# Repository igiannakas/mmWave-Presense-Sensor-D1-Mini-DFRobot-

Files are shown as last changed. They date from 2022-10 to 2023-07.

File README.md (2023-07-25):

# Introduction
This is a step by step guide on how to build an mmWave presence detection using DFRobot SEN0395, D1 Mini ESP-8266 and ESPHome. 

The custom module in the code above is used to implement a room presense sensor and exposes the presense detection sensor and the radar's configuration variables to Home Assistant via the ESPHome integration.

For a more advanced multi-sensor, including temperature, humidity, air quality and air pressure refer to my project here: https://github.com/igiannakas/Presense-Temperature-Humidity-Air-Quality-multi-sensor-DFRobot-SHT35-or-BME680-

This is based on the excellent work done by CRlogic in the HA forums and documented here: https://github.com/hjmcnew/esphome-hs2xx3a-custom-component/tree/release

In this fork of the code, the code is adapted to:
1. Deliver a very compact build as the DFRobot sensor is stacked on top of the D1 Mini
2. Trimmed down the code by CRLogic to improve stability for the low power D1 Mini. The sensor is purely focused on presense and motion detection, which is the core use case.
3. Prettify the exposed sensor names to Home Assistant to reflect the name of the room the sensor is in
4. Contain the full sensor yaml configuration to simplify the setup process

# Bill of Materials:
To make this DIY room presense sensor you'll need the below components:
1. D1 Mini
2. DFRobot SEN0395 (from Digi Key, Mouser, Arrow.com, Farnell.com, AliExpress)
3. Mini USB cable and a USB power supply (I use my old phone chargers)
4. Soldering iron
5. 5 cm / 2 inch of wire
6. Optional: 3d printed case (either the one in the folder above or the slightly larger case I've published here if you are using an ESP32 Mini: https://www.printables.com/model/520547-esp32-temperature-and-optional-mmwave-radar-presen)

# Wiring instructions:
To get the smallest possible size we stack the sensor on top of the D1 Mini using the pins that come with the D1 mini. The wiring diagram below reflects a stacked configuration:
Sensor Pin -> D1 Mini Pin
1. TX -> D1
2. RX -> D2
3. IO1 -> not connected
4. IO2 -> D0 (using the wire)
5. G -> G
6. V -> 5V

For the D1, D2, G and 5V pins we will use header and pin connectors soldered on the D1 mini and the mmWave sensor. The D0 - IO2 connection happens via a wire which is soldered on the D0 pad of the D1 mini and the IO2 pad of the sensor.

# Assembly images

Solder the header connectors and the single wire to the D1 Mini as below:
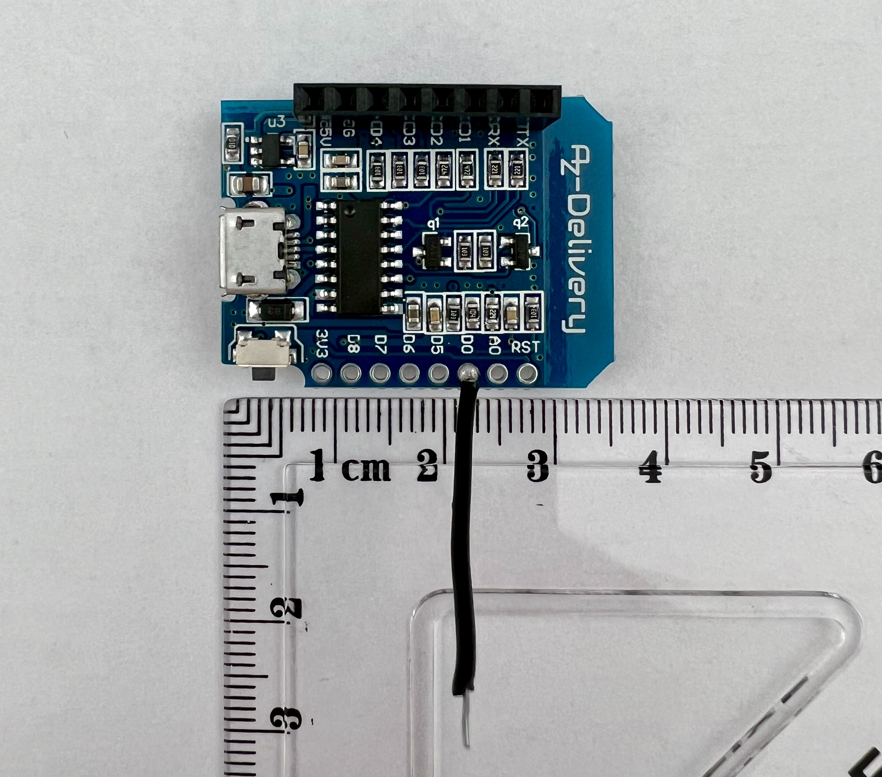
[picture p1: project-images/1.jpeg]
D1 Mini connections


Solder the pins to the outer two sets of pads on the sensor (TX, RX, G, V) and then solder the single wire to IO2
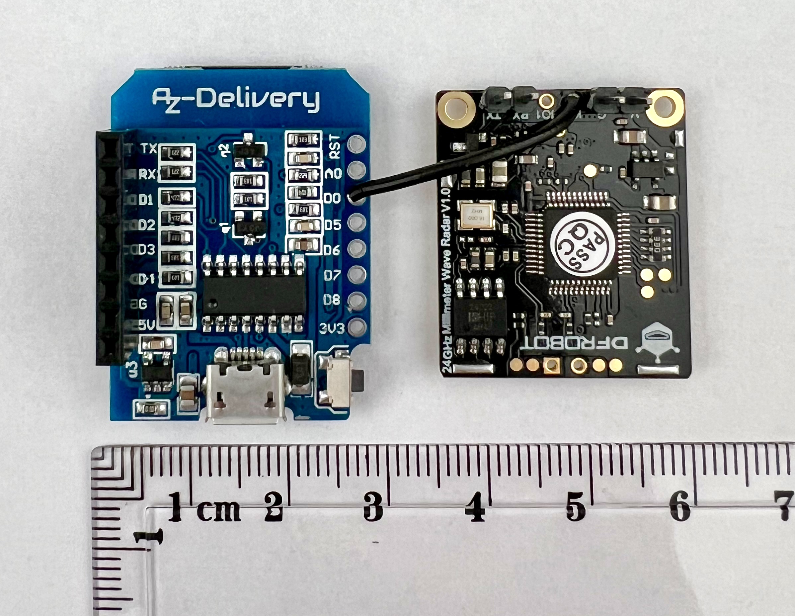
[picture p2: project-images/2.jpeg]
Sensor connections


Plug in the sensor to the D1 mini,making sure the V sensor pin is aligned to the 5V header on the D1 mini
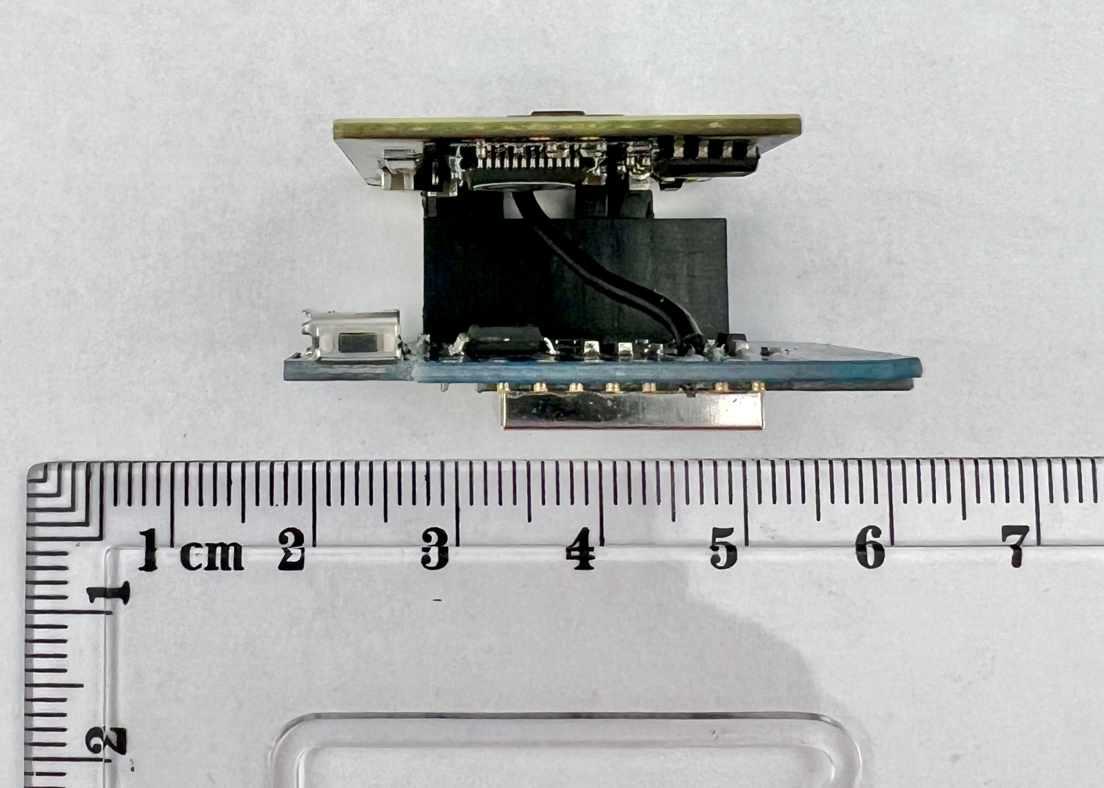
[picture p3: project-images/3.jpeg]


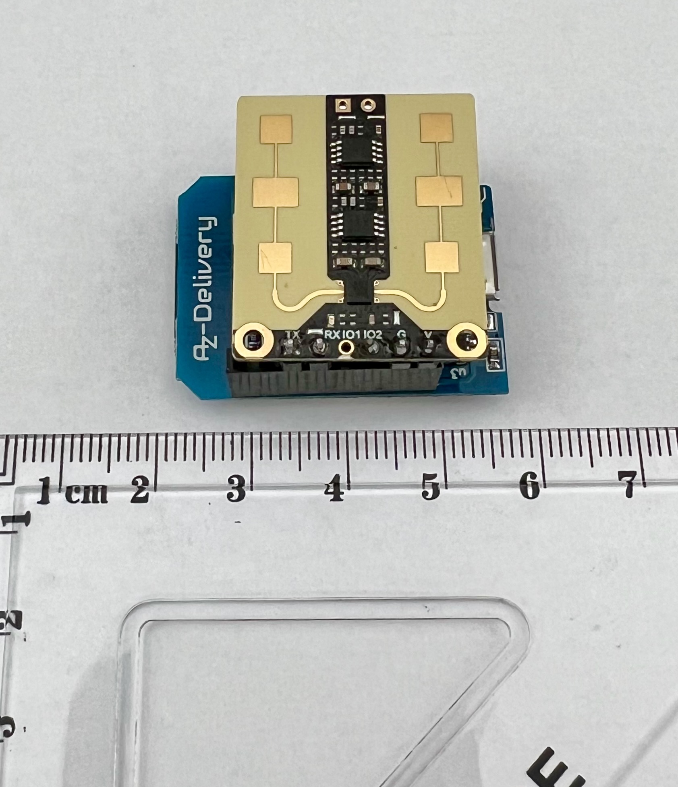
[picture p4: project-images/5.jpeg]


As you can see this is a super compact sensor, barely bigger than the D1 mini itself.
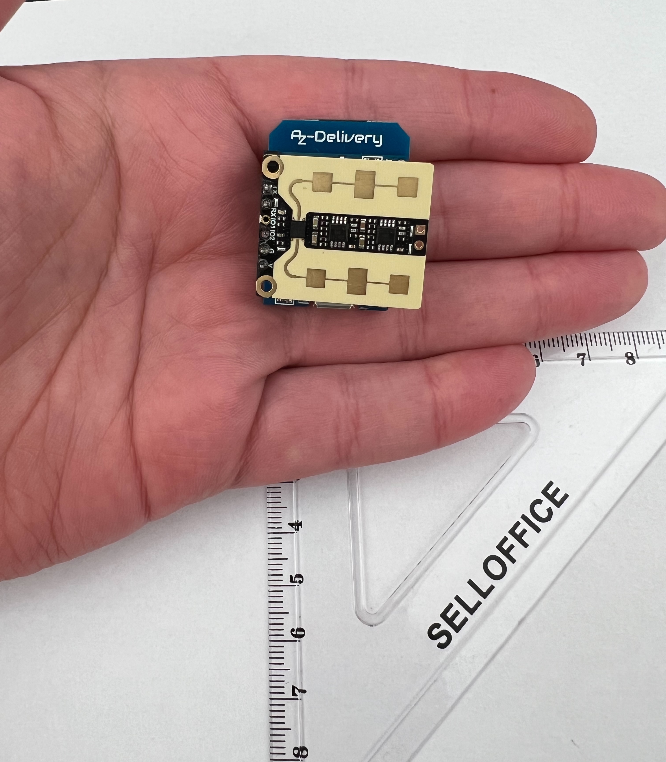
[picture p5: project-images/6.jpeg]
Sensor assembled


# Installing ESPHome and the mmWave code

1. Setup your esphome environment. For instructions: https://esphome.io
2. Clone this repository to your build environment. Download the code zip and unpack it in your esphome build directory
3. Open the sensor.yaml file and modify the following variables to match your setup:

**device_name**: the sensor's device name. This must be in lower case and any words separated with hyphens (-). For example: living-room-occupancy-sensor<br>
**device_name_pretty**: This is the name of the occupancy binary sensor that will be exposed to home assistant. It can be upper and lower case and can contain spaces. For example: Room Name Occupancy Sensor<br>
**ssid**: type your 2.4ghz wifi SSID<br>
**wifi_password**: type in your wifi password<br>

4. Do not modify the uart_tx_pin, uart_rx_pin, gpio_pin values unless you're using a different pinout connection.
5. Deploy the code. I have installed esphome on my mac so I use the following command to deploy the code: esphome run sensor.yaml . If it is a fresh D1 Mini, it doesnt contain the esphome code. For the first flash, you'll need to plug it in to your computer or HA box and flash it. Any subsequent updates will happen over the air. 

For a tutorial on how to setup your esphome instance read up here:
1. From the command line & using docker: https://esphome.io/guides/getting_started_command_line.html
2. From home assistant OS: https://esphome.io/guides/getting_started_hassio.html

# Setting the sensor up in HomeAssistant and configuring its parameters
The sensor should be autodetected in your homeassistant dashboard. Go to Settings - Devices & Services and add the integration. Then you should be presented with the following device dashboard:

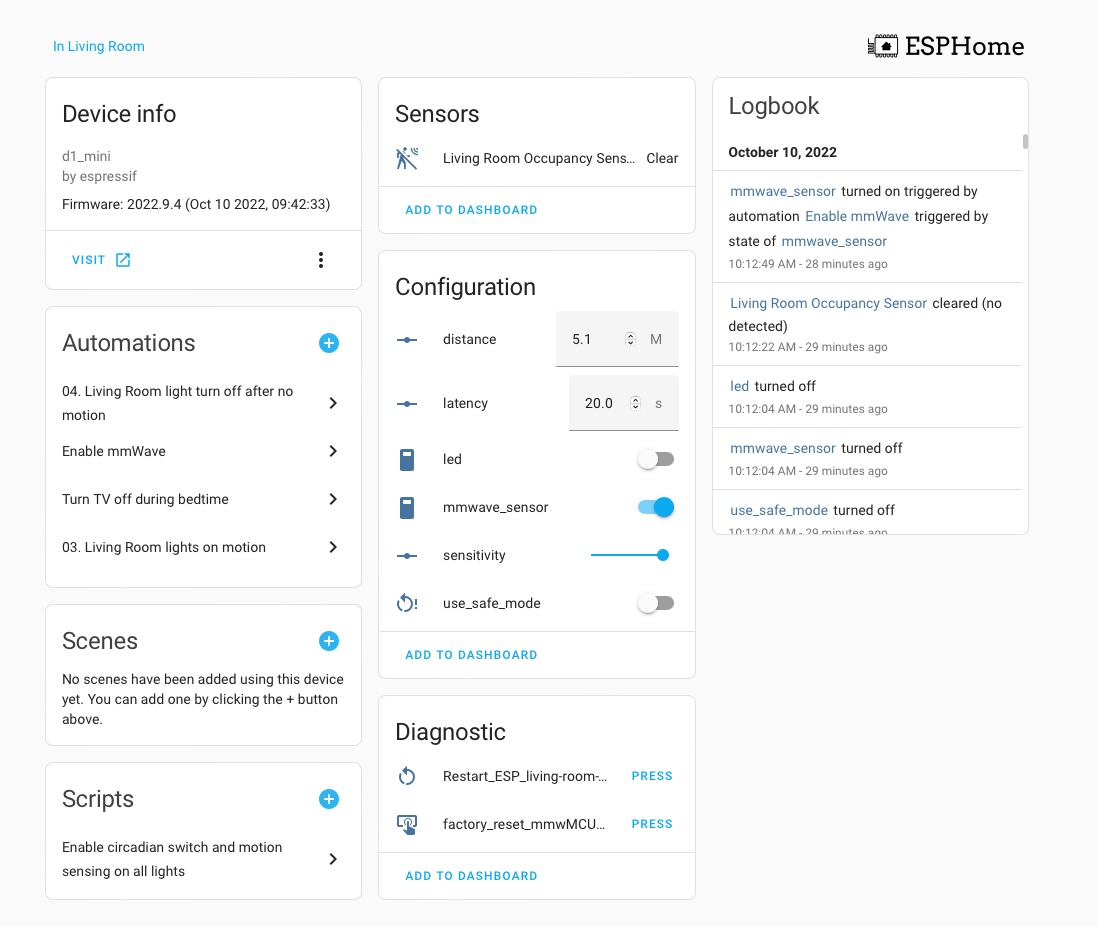
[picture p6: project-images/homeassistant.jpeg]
Homeassistant dashboard


Here you can:
1. **See the occupancy sensor value (clear / detected)**. This is the sensor you will use in your automations. 
2. **Distance**: this variable can be used to set the maximum distance the sensor can see. It defaults to the sensor default value.
3. **Latency**: this is the sensor cool down period, i.e. how long should no presence be detected before the occupancy sensor is set to "Clear". It defaults to the sensor default value.
4. **Led**: a toggle switch to turn the sensor LED on or off. On initial setup it defaults to off but the sensor LED is on and blinking. So if you want to turn the sensor LED off, switch it on, wait for 10 seconds then switch it off again. The value should now persist in the sensor's memory
5. **mmwave_sensor**: This toggle switch turns the motion sensor (radar) on or off. It defaults to on, but is reported as off until the first time presense is detected. Can be usefull if you need to disable motion sensing from an automation or script.
6. **Sensitivity**: How sensitive the sensor is to movement. The Radar sensor is **very** sensitive to movement in order to deliver meaningfull presense detection but it can be triggered falsely with the movement of curtains, clothes etc. If you want to reduce sensitivity reduce this number. It defaults to 7, which is a good balance but if you are finding that the sensor reporting as clear when the room is occupied increase this to 9.
7. **use_safe_mode**: restarts the D1 mini in safe mode
8. **Restart**: restarts the sensor
9. **Factory reset mmWMCU**: resets the radar to its factory default settings. (distance, latency, led, sensitivity)

The sensor distance, latency, mmwave_sensor, sensitivity values are read from the radar's presistent memory. They persist reboots but reporting the values to HomeAssistant is delayed. It will take 5-10 minutes after you reboot the D1 Mini for the values to be reported so be patient until they are populated before making any changes.

Every time you change a value you need to wait ~15 - 20 seconds for the value to be written to the DFRobot radar sensor memory and for the radar to restart. While the D1 mini is writing the values to the radar's memory you'll see the LED light turn red. Once it starts blinking or is off (depending on your settings) the values are now written in memory and are persistent through reboots. 

# Sensor case
I've designed a basic case for the sensor which should provide a snug fit to its components. The STL file is included in the respository above. The case has been tested with the D1 mini and the above sensor and also with a D1 mini and an LD2410 mmwave sensor.

There are two linds in the file - a tight and a loose fitting one. Depending on your 3d Printer tolerance print one of the two lids to allow for friction fit.

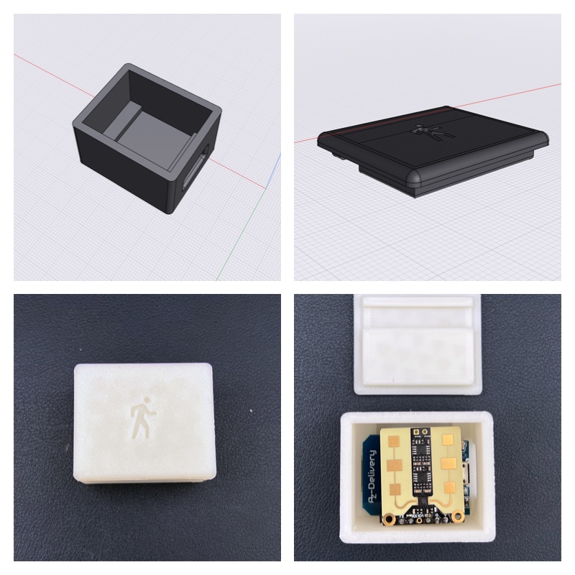
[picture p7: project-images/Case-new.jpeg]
Case


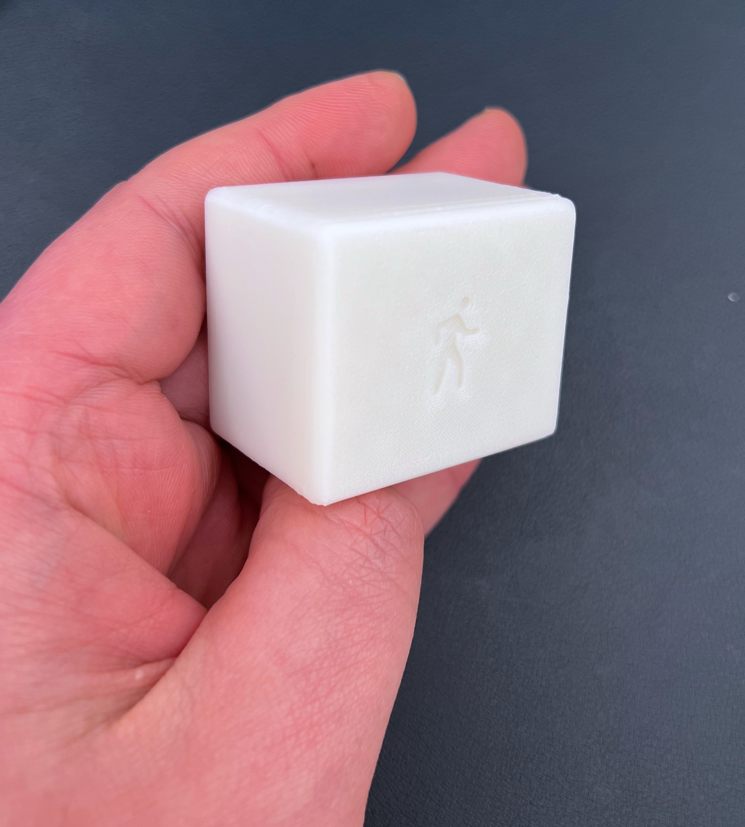
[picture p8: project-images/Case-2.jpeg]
Case


# Troubleshooting
What I have found is that the sensor is very sensitive to motion (which is what you want in order to get room presense). However, that might lead to false positives, when for example, you have a window open and objects move. 

In that situation, your best bet is to experiment with placement, the distance parameter and lastly if everything else fails, the sensitivity parameter. You dont want sensitivity too low, as it wont be able to detect the micro movements that humans do when siting around though!

Also if you are sleeping on the sofa and covered with a blanket the sensor might not detect you - a larger cooldown period (latency) can help here but you're trading off the lights being on for longer when noone is actually present.

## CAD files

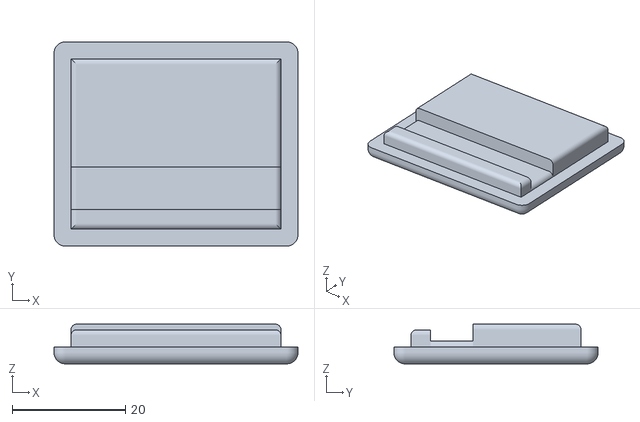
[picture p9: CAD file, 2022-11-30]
Case STL model/mmWave lid tight - v7.stl
43.0 x 36.0 x 7.00

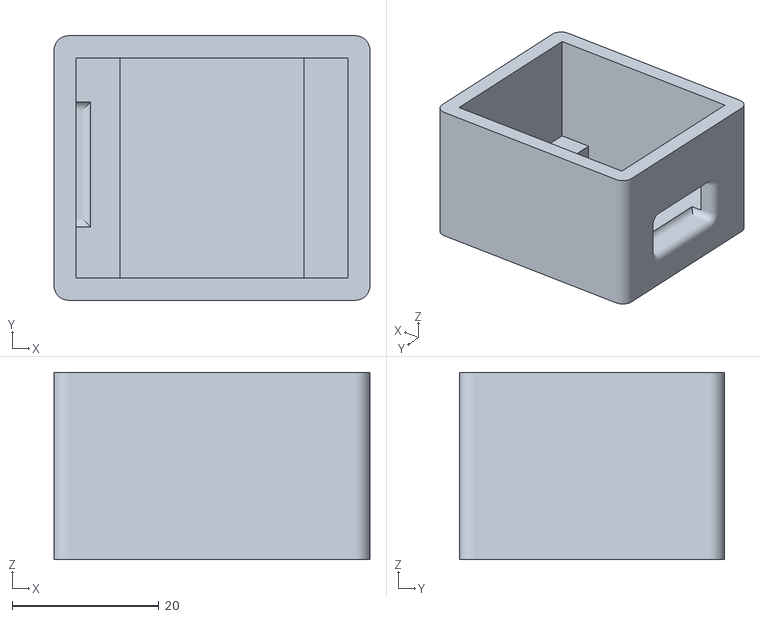
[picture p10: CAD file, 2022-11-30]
Case STL model/mmWave bottom case v7.stl
43.0 x 36.0 x 25.5

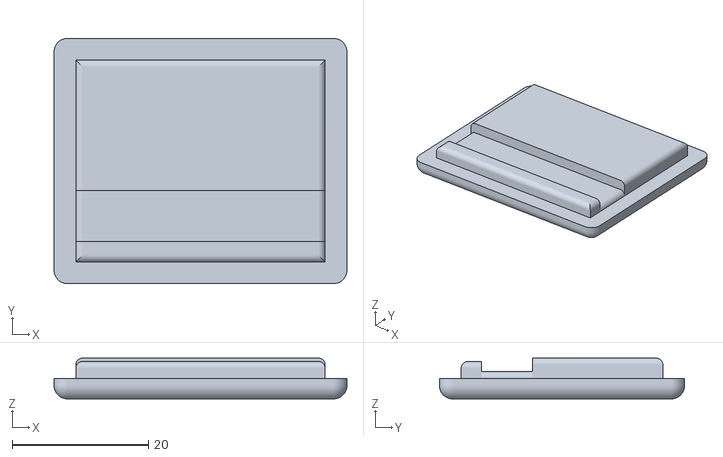
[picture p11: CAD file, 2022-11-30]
Case STL model/mmWave lid loose - v7.stl
43.0 x 36.0 x 6.00

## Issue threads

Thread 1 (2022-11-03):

A esp32 d1 mini is perfect

stofakiller, 2022-11-03:
Hi, i tried a esp32 d1 mini, with 2 rows of pins on either side. and i can connect the sensor directly. pin 21/22 for rx/tx, 16/17 for the IO1 (not used) and IO2 from the sensor and vcc and gnd...
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

Ramblurr, 2022-12-30:
@igiannakas Would you be willing to help scale the STL to fit the esp32 d1 mini? I'm not very talented with CAD unfortunately.

My calipers tell me that the ESP32 d1 mini PCB is 31.78 mm wide x 39.09mm long. If you measure the length from one end of the PCB to the other and include the micro usb socket then the length is about 39.9mm

igiannakas, 2022-12-30:
> @igiannakas Would you be willing to help scale the STL to fit the esp32 d1 mini? I'm not very talented with CAD unfortunately.
>
> My calipers tell me that the ESP32 d1 mini PCB is 31.78 mm wide x 39.09mm long. If you measure the length from one end of the PCB to the other and include the micro usb socket then the length is about 39.9mm

Should be able to scale it up to the size you want in your 3D printer slicer? No need for CAD to bump up its dimensions?

nickelnine, 2023-01-19:
@stofakiller , did you happen to print a case to fit the ESP32 version?

stofakiller, 2023-01-20:
Hi,Sorry not Venlig hilsen/Best Regards,Jan LarsenDen 20. jan. 2023 kl. 00.50 skrev nickelnine ***@***.***>:
@stofakiller , did you happen to print a case to fit the ESP32 version?

—Reply to this email directly, view it on GitHub, or unsubscribe.You are receiving this because you were mentioned.Message ID: ***@***.***>

Closed 2022-11-30.

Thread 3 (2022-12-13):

combine in one yaml

smic717394, 2022-12-13:
First of all, thank you for the detailed post. The way it worked for me was creating a folder called mmwave in the esphome directory just to organise things, inside I copied the 2 folders header and packages. I had to modify the path in the yaml to the mmwave/packages/leapmmw_sensor.yml and then edited the sensor yaml and change the header path to mmwave/header/leapmmw_sensor.h, I guess I could just puth both header and sensor in one folder.

I have 2 questions, Would it be posible to combine the sensor and header in one yaml that flases into the mini d1, and second, in case this is not posible, say you have 3 units, do I need to create 3 folders with 3 sensor.h and sensor.yml files, o could I just redirect all to the same path?

igiannakas, 2023-07-25:
They can all redirect to the same path - that is the reason why I split them out to multiple files. You only need one "sensor.yaml" per sensor. They can all be in the root directory, with the remaining items (.h / leapmmw_sensor.yml) reused.

Closed 2023-07-25.

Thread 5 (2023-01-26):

Settings wont be saved

fwartner, 2023-01-26:
I have a problem with saving the settings.
Once I reload the page, the settings I made are gone. Either in HA or the webinterface.

Running on the latest esphome version: 2022.12.7

igiannakas, 2023-01-26:
Try waiting a few seconds between changing one setting and then changing another. The radar needs time to save each one individually.

fwartner, 2023-01-27:
Doesn't have any effect.. :-/

igiannakas, 2023-01-27:
It may be a wiring issue - can you post a screenshot from the complete HA device page? Are you seeing the sensor reporting back the preset distance and sensitivity values in home assistant?On 27 Jan 2023, at 08:53, Florian Wartner ***@***.***> wrote:
Doesn't have any effect.. :-/

—Reply to this email directly, view it on GitHub, or unsubscribe.You are receiving this because you commented.Message ID: ***@***.***>

fwartner, 2023-01-27:
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

Nothing really changed when I try to update anything. Like I said yesterday.. Once I reload the page, any setting is resettet.

fwartner, 2023-01-27:
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

igiannakas, 2023-01-27:
As you are not seeing the default values in the home assistant dashboard it is a connection error. Check that the wiring is done correctly - tx to rx and vice versa and that the motion detection pin is connected correctly.On 27 Jan 2023, at 09:06, Florian Wartner ***@***.***> wrote:

—Reply to this email directly, view it on GitHub, or unsubscribe.You are receiving this because you commented.Message ID: ***@***.***>

igiannakas, 2023-01-27:
This happens because serial communication is not established. This is usually due to a wiring issue or your pin out in the config is wrong.

fwartner, 2023-01-28:
I was indeed the wiring ^^'

Thank you for the help you provided!

Closed 2023-01-28.

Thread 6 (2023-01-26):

HA shows me always recognized

fwartner, 2023-01-26:
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

It's actually useless..

igiannakas, 2023-01-26:
Check if your radar is not picking up micro motions from a fan, air drafts, moving clothing etc. reduce sensitivity on the radar.

have been using them for the past 6 months and they have been reliable so the code is working, but the setup needs tweaking.

fwartner, 2023-01-27:
Nah.. Doesn't work.. :-/

ivishaltejwani, 2023-05-04:
> Check if your radar is not picking up micro motions from a fan, air drafts, moving clothing etc. reduce sensitivity on the radar.
>
> have been using them for the past 6 months and they have been reliable so the code is working, but the setup needs tweaking.

any idea how to change sensitivity on arduino ide , example through blynk slider?

Closed 2023-01-28.

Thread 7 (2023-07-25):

Can't change names of distance, latency, or sensitivity sensors

Mike1082, 2023-07-25:
First of all, thank you for sharing this. Out of the box for one sensor it works amazingly well.

My issue is that I would like to run many of these. When I deploy the first one, my friendly name does not get used for the distance, latency, or sensitivity sensors. For instance, "distance" is just called "number.distance" as opposed to "number.sensor-name-distance". I tried updating the leapmmw_sensor.yml file by changing the names (while leaving the id as-is) but with the 3 mentioned sensors, once I change those names, they will no longer update in HA with values stored in the device. They just look empty, even after waiting a very long time.

I tested this by going back and one-by-one putting the original "names" back, and as I did that, the values started appearing in HA and working as expected.

I believe that the issue is the functions in the header file are referring to the Name, as opposed to the id.

For example from leapmmw_sensor.yml:

```
number:
  - platform: template
    name: ${device_name_pretty} Distance #original value: distance
    id: distance # do not change
    entity_category: config
    min_value: 0.15
    max_value: 9.45
    step: 0.15
    unit_of_measurement: M
    mode: box
    lambda: |-
      leapmmw(id(uart_bus)).getmmwConf("getRange");
      return {};
    set_action:
      - switch.turn_off: mmwave_sensor
      - delay: 2s
      - uart.write: !lambda
          std::string range = "setRange 0 " + str_sprintf("%.2f", x);
          return std::vector<unsigned char>(range.begin(), range.end());
      - delay: 3s
      - switch.turn_on: mmwave_sensor
```

and from leapmmw_sensor.h:

```
// leapMMW:/>getRange
          if (getline.substr(0, 18) == "leapMMW:/>getRange" || getline.substr(0, 8) == "getRange") {
            std::string getRange = line.substr(15, 4);
            if (getRange.empty()) {
              ESP_LOGD("custom", "Did not find a value for getRange");
            } else {
              ESP_LOGD("custom", "The value of getRange is: %f", parse_number<float>(getRange).value());
              publishNumber("distance", parse_number<float>(getRange).value());
            }
          }
```

Once I change the "name" in the yml file, the function `publishNumber("distance", parse_number<float>(getRange).value());` no longer seems to work.

Is there a better way to have all of the entities associated with the device have names prefixed with the device name?

Thanks!

igiannakas, 2023-07-25:
Excellent,
Glad it worked as well for you! I’ve also deployed it on my setup too :)

Mike1082, 2023-07-25:
I was going to ask about adding additional sensors, then I realized you have another device with temp/humidity and another STL for a case... you f'in rock man. Is there any reason I couldn't do the same thing without going to an ESP32 version of the D1? I just bought a pack of D1 Minis with USB-C and 8266. They should be able to support one more sensor, and maybe a push button, right?

igiannakas, 2023-07-25:
Hey! Yes you can do it with an esp8266 - the wiring is a bit more tight space wise but it works ok.

The only reason i went for an esp32 for the combo sensor is because I wanted to try an esp32!

The same code from the other repo should work if you replace the pins with the ones your 8266 uses.

igiannakas, 2023-07-25:
Ps. If you try the other case with an 8266 you’ll need to enlarge the square cut out for the chip a bit as the d1 mini has it moved more to the left compared to the esp32 mini. I’ve included the step files on printables so it should be a very quick mod.

Closed 2023-07-25.

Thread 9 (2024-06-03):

Detection Segment Support

54Comet, 2024-06-03:
https://esphome.io/components/dfrobot_sen0395.html

> detection_segments (Optional, list): A list of detection segments. A segment specifies from where to where detection should trigger. One to four segments and ranges from 0cm to 9m may be specified. Distances should be defined in steps of 15cm. Note that the specified ranges are rounded internally. Segments can be defined in a one or two dimensional list. Pairs of values must be defined (from distance to distance). The default is one range from 0cm to 3m.

Would it be possible for this project to allow configuring the up to 4 detection segments that the sen0395 supports?  Currently I think the `id: distance` variable is essentially allowing a single segment to be set.

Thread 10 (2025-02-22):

Esp home 2025 does not allow custom components anymore

napalmcsr, 2025-02-22:
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

INFO ESPHome 2025.2.0
INFO Reading configuration /config/esphome/Family-room-mmPresence.yaml...
Failed config

sensor.custom: [source /config/esphome/mmwave-d1mini-main/packages/leapmmw_sensor.yml:40]

  The "custom" component has been removed. Consider conversion to an external component.
  https://esphome.io/guides/contributing#a-note-about-custom-components.
  platform: custom
  lambda: auto s = new leapmmw(id(uart_bus));
  App.register_component(s);
  return {};
  sensors:

napalmcsr, 2025-02-22:
I don't have the expertise to fix this... Maybe someday...

momoz, 2025-03-11:
anyone look through this and have a fix?

igiannakas, 2025-03-12:
Hi there thank you for this. I hadn’t compiled my sensors in a while as they have been working fine. Just seen that this is now deprecated.

I’ll update the repo over the next few days hopefully to address this.

DrFate09, 2025-03-15:
I was able to fix my presence sensor by using the fixed code for ESP here, https://github.com/DuncanIdahoCT/DFRobot-mmWave-Radar-dfrobot_sen0395

scotti-fletcher, 2025-05-14:
@DrFate09 would you mind sharing your code?

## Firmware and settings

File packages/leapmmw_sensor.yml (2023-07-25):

substitutions:
  # include the header file with the UART parsing logic 
  header_file: header/leapmmw_sensor.h

esphome:
  name: ${device_name}
  includes:
    - ${header_file}

#logger:
#  logs:
#    sensor: DEBUG # reduced logging to minimize web_server target overload..

uart:
  id: uart_bus
  tx_pin: ${uart_tx_pin}
  rx_pin: ${uart_rx_pin}
  baud_rate: 115200


## sensor definitions

binary_sensor:
  - platform: gpio
    name: "${device_name_pretty}"
    id: mmwave_presence_detection
    device_class: motion
    pin:
      number: ${gpio_pin}
      mode: INPUT_PULLDOWN
    # when motion is detected, the radar sensor is on so publish radar state to HA
    on_press:
      then:
        lambda: !lambda |-
          if (!id(mmwave_sensor).state) {
            id(mmwave_sensor).publish_state(true);
          }
    
sensor:      
  - platform: custom
    lambda: |-
      auto s = new leapmmw(id(uart_bus));
      App.register_component(s);
      return {};
    sensors:
      
switch:
  - platform: safe_mode
    name: use_safe_mode

  - platform: template
    name: "${device_name_pretty} mmwave_sensor"
    id: mmwave_sensor # do not change
    entity_category: config
    optimistic: true
    turn_on_action:
      - uart.write: "setUartOutput 1 0"
      - delay: 1s
      - uart.write: "saveConfig"
      - delay: 4s 
      - uart.write: "sensorStart"
    turn_off_action:
      - uart.write: "sensorStop"
      - delay: 2s

  - platform: template
    name: "${device_name_pretty} led"
    id: led  # do not change
    entity_category: config
    optimistic: true
    turn_on_action:
      - switch.turn_off: mmwave_sensor
      - delay: 2s
      - uart.write: "setLedMode 1 0"
      - delay: 3s
      - lambda: |-
          leapmmw(id(uart_bus)).getmmwConf("getLedMode 1");
      - delay: 2s 
      - switch.turn_on: mmwave_sensor
    turn_off_action:
      - switch.turn_off: mmwave_sensor
      - delay: 2s
      - uart.write: "setLedMode 1 1"
      - delay: 3s
      - lambda: |-
          leapmmw(id(uart_bus)).getmmwConf("getLedMode 1");
      - delay: 2s
      - switch.turn_on: mmwave_sensor 

number:
  - platform: template
    name: "${device_name_pretty} distance"
    id: distance # do not change
    entity_category: config
    min_value: 0.15
    max_value: 9.45
    step: 0.15
    unit_of_measurement: M
    mode: box
    lambda: |-
      leapmmw(id(uart_bus)).getmmwConf("getRange");
      return {};
    set_action:
      - switch.turn_off: mmwave_sensor
      - delay: 2s
      - uart.write: !lambda
          std::string range = "setRange 0 " + str_sprintf("%.2f", x);
          return std::vector<unsigned char>(range.begin(), range.end());
      - delay: 3s
      - switch.turn_on: mmwave_sensor 
      
  - platform: template
    name: "${device_name_pretty} latency"
    id: latency # do not change
    entity_category: config
    min_value: 1
    max_value: 600
    lambda: |-
      leapmmw(id(uart_bus)).getmmwConf("getLatency");
      return {};
    step: 1
    unit_of_measurement: s
    mode: box
    set_action:
      - switch.turn_off: mmwave_sensor
      - delay: 2s
      - uart.write: !lambda
          std::string setL = "setLatency 0.1 " + str_sprintf("%.0f", x);
          return std::vector<unsigned char>(setL.begin(), setL.end());
      - delay: 3s
      - switch.turn_on: mmwave_sensor

  - platform: template
    name: "${device_name_pretty} sensitivity"
    id: sensitivity # do not change
    entity_category: config
    min_value: 0
    max_value: 9
    lambda: |-
      leapmmw(id(uart_bus)).getmmwConf("getSensitivity");
      return {};
    step: 1
    set_action:
      - switch.turn_off: mmwave_sensor
      - delay: 2s
      - uart.write: !lambda
          std::string mss = "setSensitivity " + to_string((int)x);
          return std::vector<unsigned char>(mss.begin(), mss.end());
      - delay: 3s
      - switch.turn_on: mmwave_sensor

button:
  - platform: restart
    name: Restart_ESP_${device_name}
    entity_category: diagnostic
    on_press:
      - uart.write:
          id: uart_bus
          data: "resetSystem 0"

  - platform: template
    name: factory_reset_mmwMCU_${device_name}
    id: factory_reset_mmwMCU
    entity_category: diagnostic
    on_press:
      - switch.turn_off: mmwave_sensor
      - delay: 2s
      - uart.write: "resetCfg"
      - delay: 3s
      - switch.turn_on: mmwave_sensor

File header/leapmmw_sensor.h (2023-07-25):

#include "esphome.h"
#include <string>


class leapmmw : public Component, public UARTDevice {
 public:
  leapmmw(UARTComponent *parent) : UARTDevice(parent) {}
  
  void setup() override {
    //
  }

  void publishNumber (std::string sensor, float resp) {
    auto get_numbers = App.get_numbers();
    for(int i = 0; i < get_numbers.size(); i++) {
      std::string name = get_numbers[i]->get_name();
      if(name.size() > 6 && name.find(sensor) !=std::string::npos) {
        get_numbers[i]->publish_state(resp);
      }
    }
  };

  void publishSwitch(std::string sensor, int state) {
    auto sens = App.get_switches();
    for(int i = 0; i < sens.size(); i++) {
      std::string name = sens[i]->get_name();
      if(name.size() > 2 && name.find(sensor) !=std::string::npos) {
        sens[i]->publish_state(state);
      }
    }
  };

  void getmmwConf(std::string mmwparam) {
    mmwparam = mmwparam + "\r";
    write_array(std::vector<unsigned char>(mmwparam.begin(), mmwparam.end()));
  }

  int readline(int readch, char *buffer, int len)
  {
    static int pos = 0;
    int rpos;

    if (readch > 0) {
      switch (readch) {
        case '\n': // Ignore new-lines
          break;
        case '\r': // Return on CR
          rpos = pos;
          pos = 0;  // Reset position index ready for next time
          return rpos;
        default:
          if (pos < len-1) {
            buffer[pos++] = readch;
            buffer[pos] = 0;
          }
      }
    }
    // No end of line has been found, so return -1.
    return -1;
  }
  std::string getline;

  void loop() override {
    const int max_line_length = 40;
    static char buffer[max_line_length];

    while (available()) {

      if(readline(read(), buffer, max_line_length) >= 4) {
        std::string line = buffer;

        // compare last line
        if (line.substr(0, 8) == "Response") {
          
          // leapMMW:/>getSensitivity
          if (getline.substr(0, 24) == "leapMMW:/>getSensitivity" || getline.substr(0, 14) == "getSensitivity") {
            std::string getSensitivity = line.substr(9, 1);
            if (getSensitivity.empty()) {
              ESP_LOGD("custom", "Did not find a value for getSensitivity");
            } else {
              ESP_LOGD("custom", "The value of getSensitivity is: %f", parse_number<float>(getSensitivity).value());
              publishNumber("sensitivity", parse_number<float>(getSensitivity).value());
            }
          }

          // leapMMW:/>getRange
          if (getline.substr(0, 18) == "leapMMW:/>getRange" || getline.substr(0, 8) == "getRange") {
            std::string getRange = line.substr(15, 4);
            if (getRange.empty()) {
              ESP_LOGD("custom", "Did not find a value for getRange");
            } else {
              ESP_LOGD("custom", "The value of getRange is: %f", parse_number<float>(getRange).value());
              publishNumber("distance", parse_number<float>(getRange).value());
            }
          }

          // leapMMW:/>getLatency
          if (getline.substr(0, 20) == "leapMMW:/>getLatency" || getline.substr(0, 10) == "getLatency") {
            std::string getLatency = line.substr(15, 2);
            if (getLatency.empty()) {
              ESP_LOGD("custom", "Did not find a value for getLatency");
            } else {
              ESP_LOGD("custom", "The value of getLatency is: %f", parse_number<float>(getLatency).value());
              publishNumber("latency", parse_number<float>(getLatency).value());
            }
          }

          // leapMMW:/>getLedMode
          if (getline.substr(0, 20) == "leapMMW:/>getLedMode" || getline.substr(0, 10) == "getLedMode") {
            std::string getLedMode = line.substr(11, 1);
            if (getLedMode.empty()) {
              ESP_LOGD("custom", "Did not find a value for getLedMode");
            } else {
              int led_state = parse_number<int>(getLedMode).value();
              ESP_LOGD("custom", "The value of getLedMode is: %i", led_state);
              int setled_state = -1;
              if (led_state == 1) {
                setled_state = 0;
              } else if (led_state == 0) {
                setled_state = 1;
              }
              publishSwitch("led", setled_state);
            }
          }
        }
        if (line.substr(0, 4) == "Done") {
          // leapMMW:/>sensorStop
          if (getline.substr(0, 20) == "leapMMW:/>sensorStop") {
            ESP_LOGD("custom", "sensorStop completed successfully");
            publishSwitch("mmwave_sensor", 0);
          }

          // leapMMW:/>sensorStart
          if (getline.substr(0, 21) == "leapMMW:/>sensorStart") {
            ESP_LOGD("custom", "sensorStart completed successfully");
            publishSwitch("mmwave_sensor", 1);
          }
        }
        getline = buffer; 
      }
    }
  }
};

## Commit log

2022-10-11 Refactored UART output
    Disabled presence and target messages from sensor as they were unused and to reduce load on the software UART on the D1 Mini
2022-11-30 New case (v7 stl)
2023-07-25 Allow pretty naming of device settings
    Fixing issue #7
    [leapmmw_sensor.yml]
2023-07-25 Allowing ability to prettify device configuration options in HA
    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
    [leapmmw_sensor.h]
2023-07-25 Removed unnecessary debug code
    #7 fixing
    [leapmmw_sensor.h]
